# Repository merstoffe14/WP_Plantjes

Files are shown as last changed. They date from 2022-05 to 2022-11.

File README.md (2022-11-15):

# Scientific project: Automated watering system.

For our course "Scientific project" we had to work out a system that automatically waters plants. While my colleague Wolf worked on the Mechanical side of the project, I developed the in-depth control interface (A website) on which the user is able to read out and set different parameters for each individual row of plants. 

With this website, you could also make different watering schedules (time of day, amount, ...) for each individual row of plants.

To realize this I used: Python, FastAPI, HTML, css, javascript, bootstrap, RPi.GPIO, Adafruit_GPIO.SPI, Adafruit_MCP3008

## File explanation

/WP_Plantjes/extra_docs
* RPI_pins_and_commands.txt : A file I used to remember some important commands and the * pins used on the RPI
* WP_Code dikke lijnen.pdf  : A pdf with the code flowchart
* WP_Water flow chart.pdf   : A pdf with the water flowchart
* user_manual_g1.pdf        : [The user manual](https://github.com/merstoffe14/WP_Plantjes/blob/main/extra_docs/user_manual_g1.pdf)

/WP_Plantjes/code/rpi:
* data.json        : the file where the rpi saves its data
* howto.html       : the webpage that shows when you press the how to button.
* index.html       : the homepage of the system
* init_data.json   : when there is no data.json, it copies this one. it is filled with placeholder data.
* main.py          : The main code, receives and sends everything to and from the web interface and communicates the data to the runner.py
* models.py        : Define different objects
* requirements.txt : The packages needed for the software to work (not all of these are needed, there are unused packages.)
* runner.py        : receives data from main.py. calculates and schedules everything. 

/WP_Plantjes/3d
* kast_schets.ipt  : A 3d model of the first idea.

/WP_Plantjes/images
* a couple of images of the finished/WIP project.

## User manual
We also had to make a user manual [user manual](https://github.com/merstoffe14/WP_Plantjes/blob/main/extra_docs/user_manual_g1.pdf)

## The challanges:

* We had to work with 220, 12, 5 and 3.3 Volt to control and power all the different systems.
* Converting a lot of analog signals (moisture sensors) to digital and sending those to the RPI using SPI
* Having 4, independently controlled, levels. 

## Pictures
Front view            |  Side view
:-------------------------:|:-------------------------:
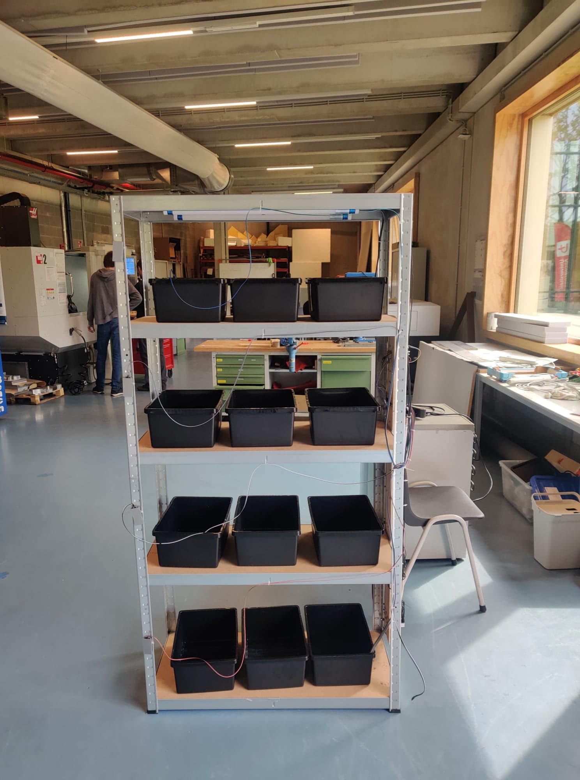
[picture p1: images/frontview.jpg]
The front view
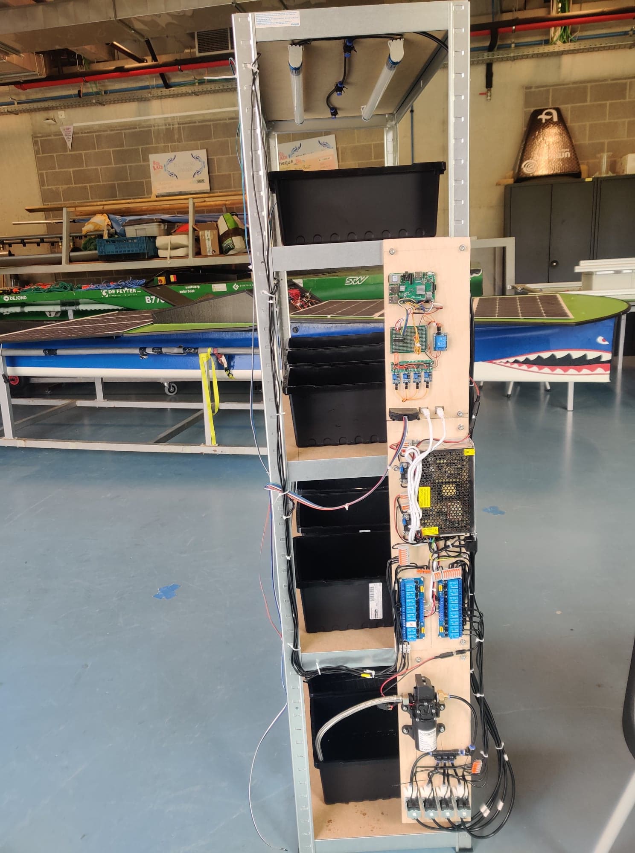
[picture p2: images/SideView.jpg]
The side view
|

Control circuitry            |  Power supply/management
:-------------------------:|:-------------------------:
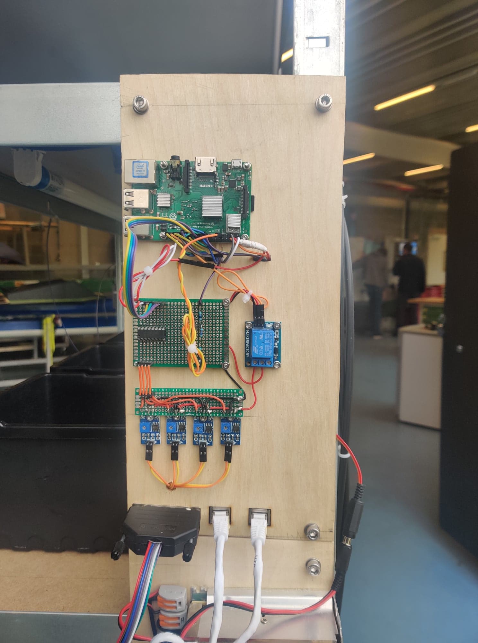
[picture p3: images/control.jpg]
Control circuits
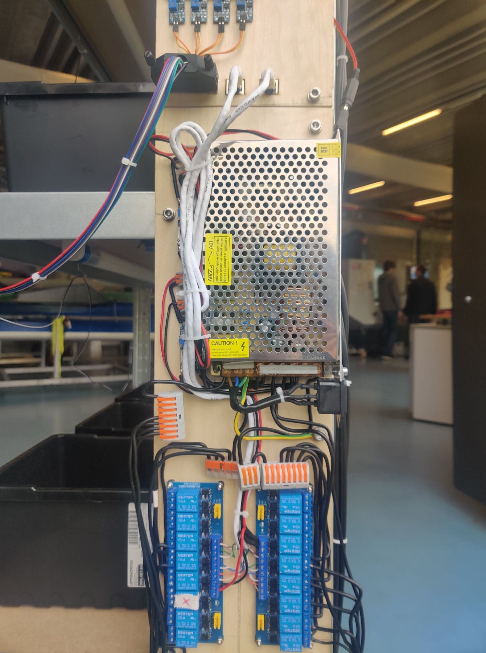
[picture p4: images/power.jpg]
Power
|

Pump and valves            |  Website
:-------------------------:|:-------------------------:
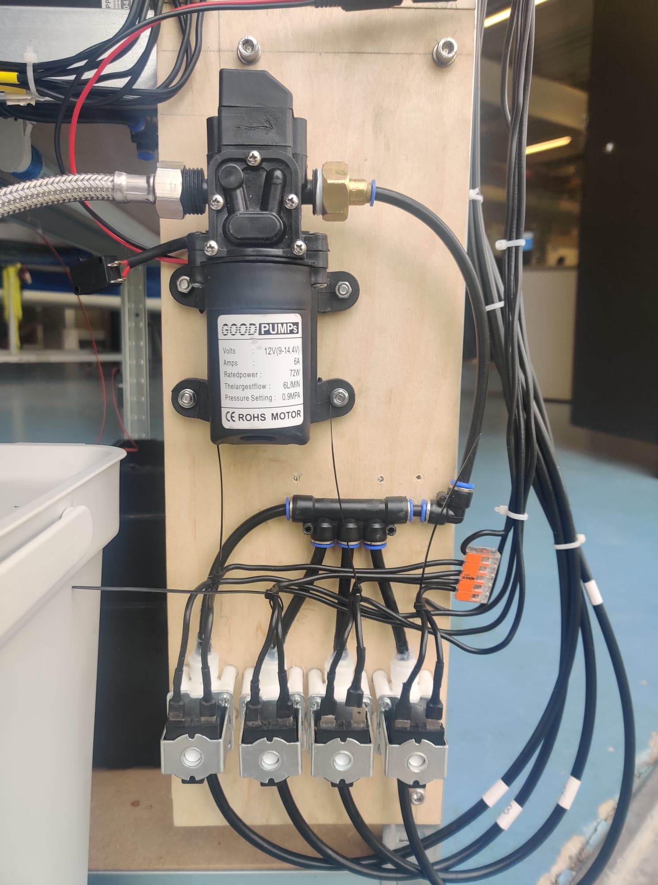
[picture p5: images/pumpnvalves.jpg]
Pump and valves
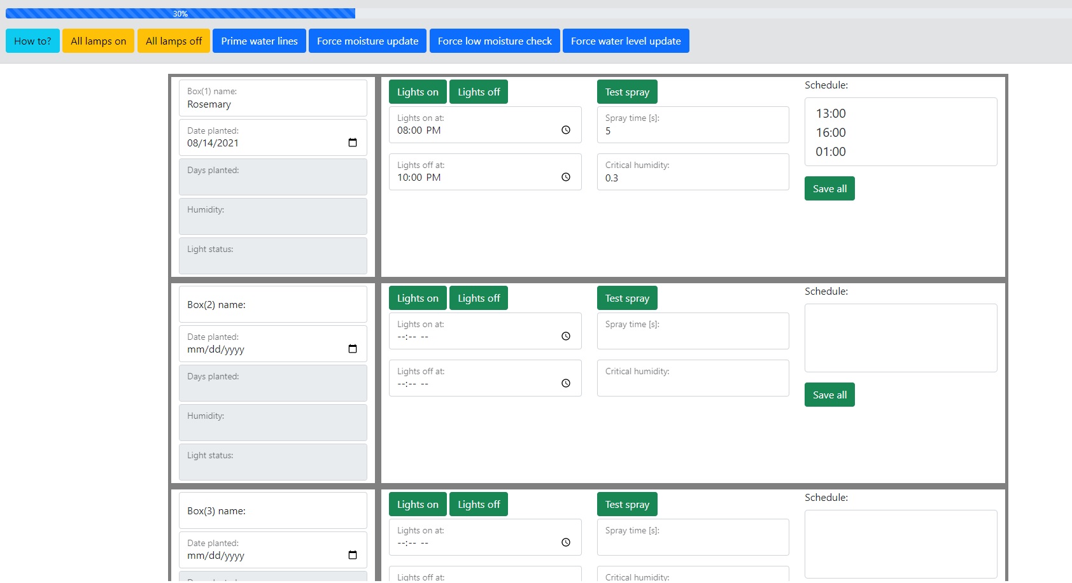
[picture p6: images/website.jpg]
Website
|

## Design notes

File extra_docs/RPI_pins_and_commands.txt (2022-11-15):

dit gaat om kabels niet verdiepen

lamp 1: 25
lamp 2: 24
lamp 3: 7
lamp 4: 1

water 1: 0 13
water 2: 5 0
water 3: 6 5 
water 4: 13 6

pomp: 19 

--MCP3008--
CLK: 4
Dout: 17
Din: 27
CS/SHDN: 22

ENABLE SENSORS: 26?

--Ultrasone--
Echo: 2
Trig: 3

raspi-config spi enablen

python -m uvicorn main:app --reload

python -m uvicorn --host 192.168.0.225 main:app

bij reset niet vergeten om account root te maken, en dan root ssh te enablen

ifconfig

sudo iwlist wlan0 scanning | grep ESSID

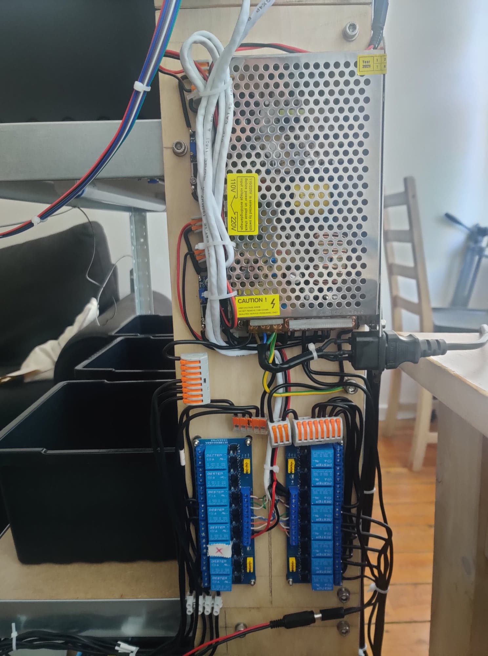
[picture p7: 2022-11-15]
images/280755883_1665423320491643_1910680200256535256_n.jpg

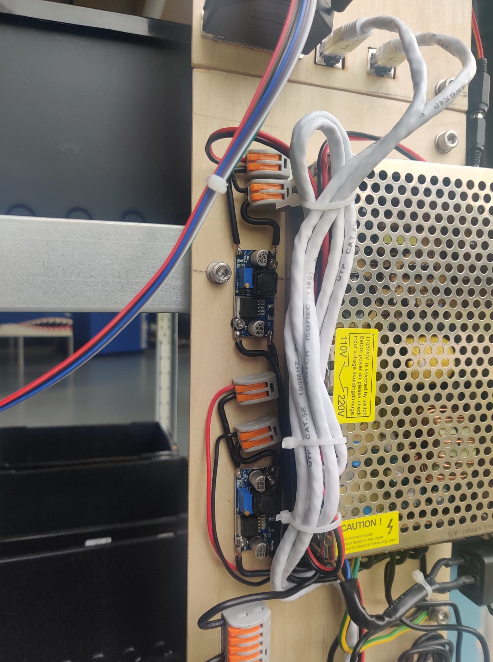
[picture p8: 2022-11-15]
images/281511996_937265423658703_378714550519950564_n.jpg

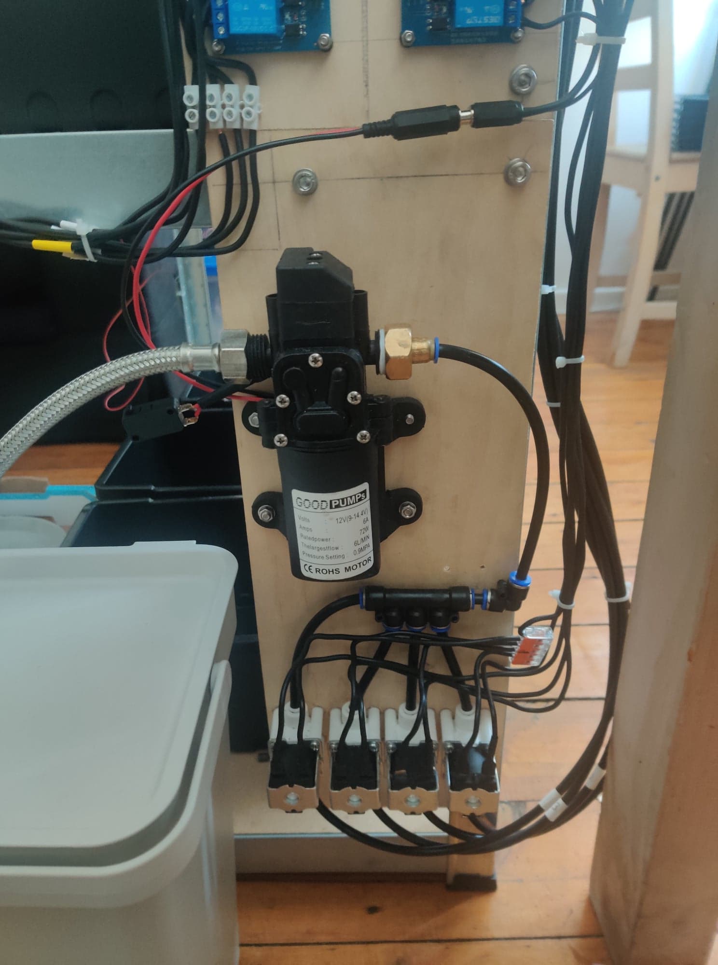
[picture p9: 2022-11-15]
images/281193448_560246208773453_215113502321909703_n.jpg

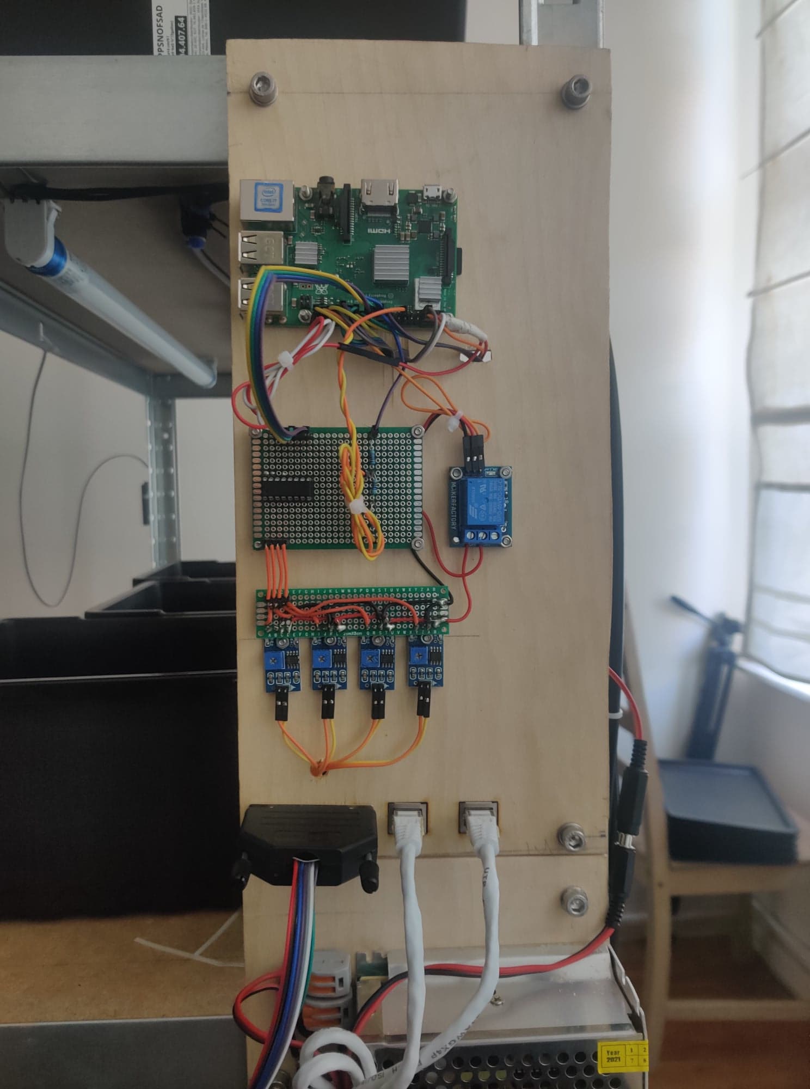
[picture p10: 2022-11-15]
images/281861318_307933138194621_1565468050905774304_n.jpg

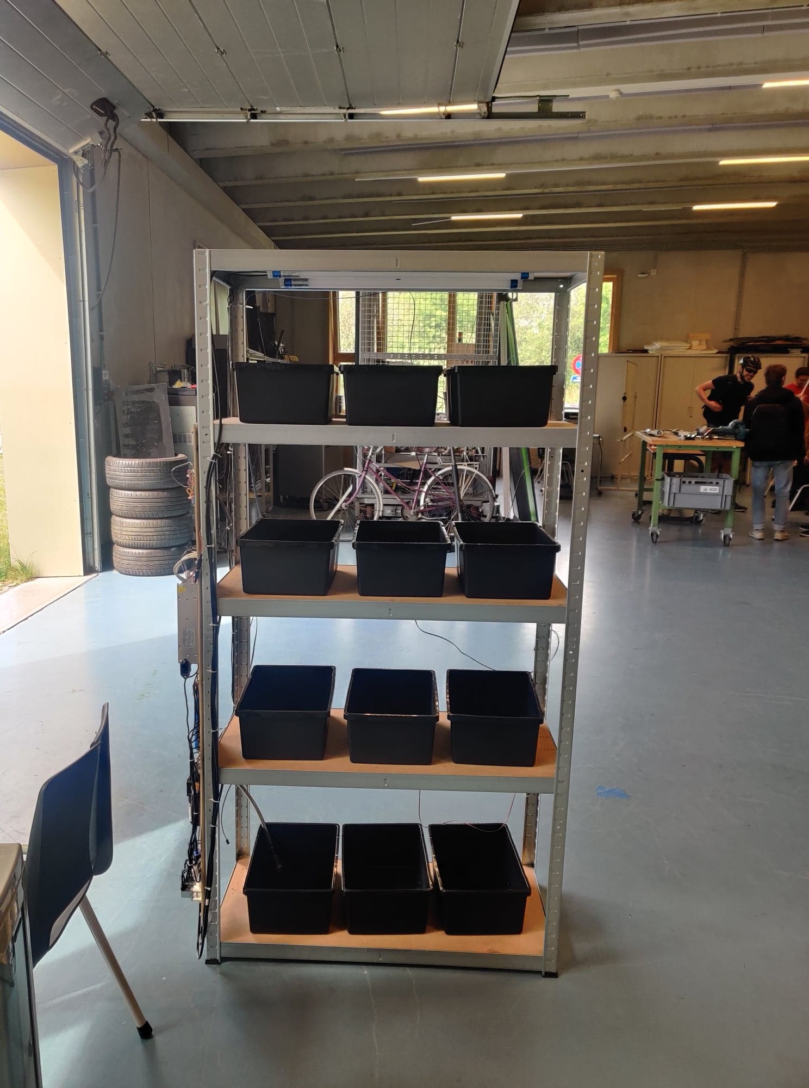
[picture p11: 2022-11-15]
images/281406808_340187884884286_5686262191399596575_n.jpg

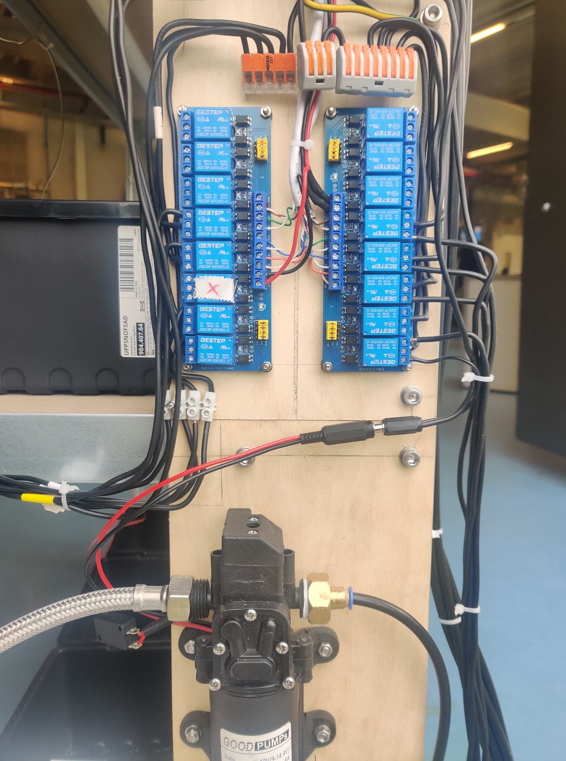
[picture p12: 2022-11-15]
images/281621734_1046185666317548_286411290797942656_n.jpg

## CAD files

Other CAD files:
3d/kast_schets.ipt

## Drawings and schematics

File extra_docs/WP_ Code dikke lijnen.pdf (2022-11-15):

## Loop User input

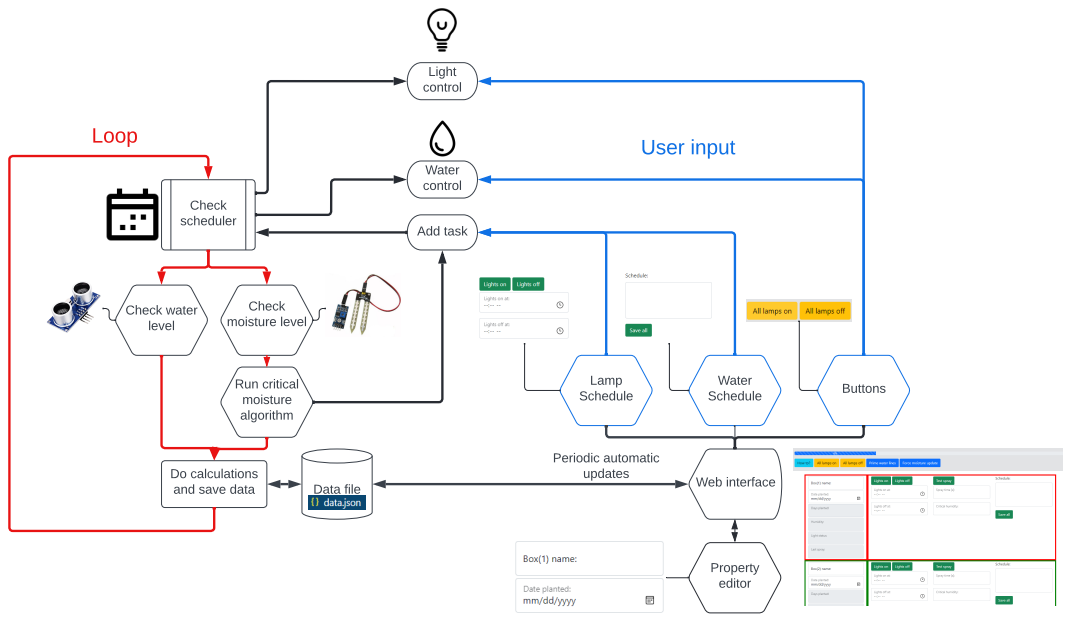
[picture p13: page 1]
Check scheduler; Add task; Check moisture level; Check water level; Light control; Water control; Run critical moisture algorithm; Do calculations; and save data; Data file; Web interface; Periodic automatic updates; Lamp Schedule; Water Schedule; Buttons; Property editor

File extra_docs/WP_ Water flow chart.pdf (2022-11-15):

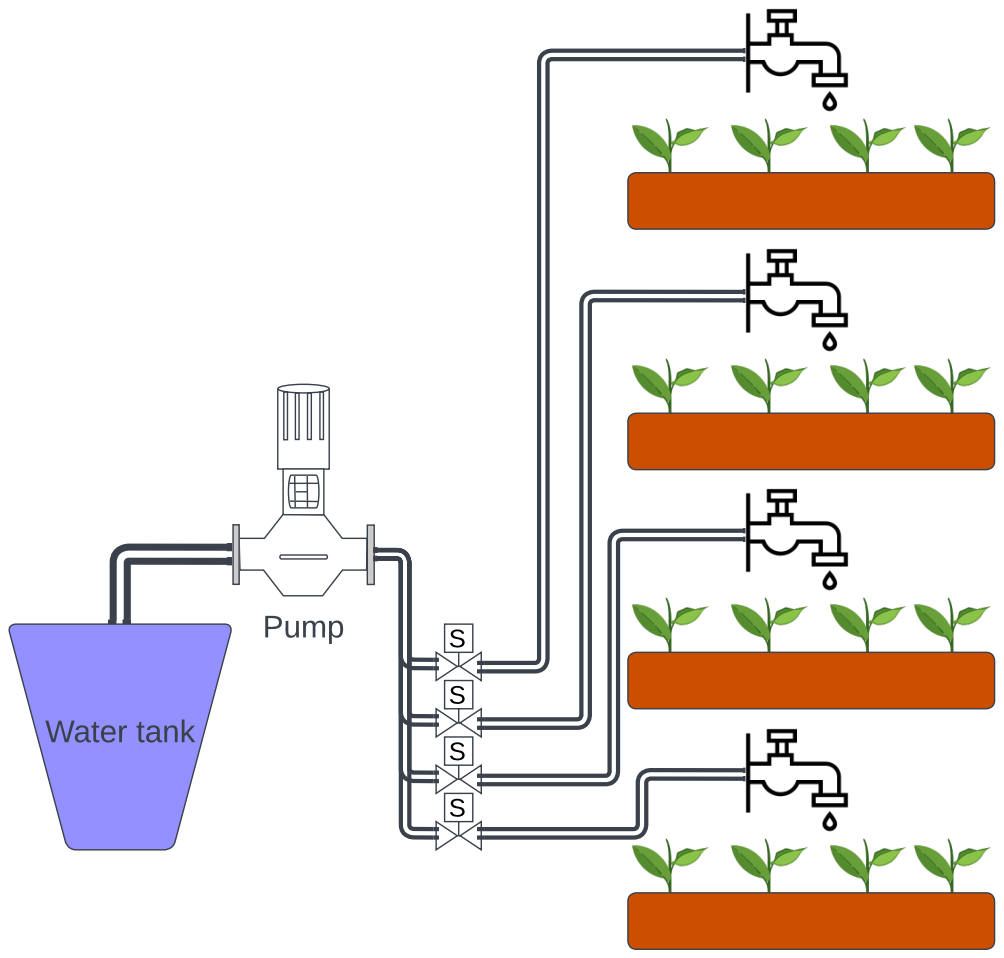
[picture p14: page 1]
SSSS

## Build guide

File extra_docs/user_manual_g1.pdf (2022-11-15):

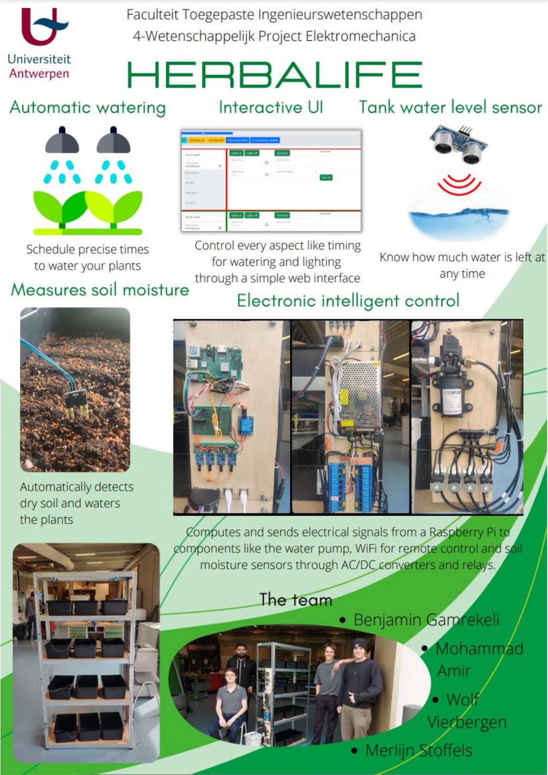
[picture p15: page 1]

# Herbalife: User manual

Table of Contents

## 1. Set up

a. Hardware set up
The set-up was not yet designed to be used by everyone; some technical knowledge is required. This could be made easier, but that was not the focus of this project.
1. Use your phone to create a hotspot with SSID “wififorpi” and password “wififorpi”
2. Plug in the power cord.
3. Wait for the lamps to turn on (Level 2 or level 3)
4. The pi automatically connects to the hotspot.
b. Software set up
1. Connect to the same network as the raspberry pi (your own hotspot).
2. Find the Pi’s local network address using a network scanner
3. Using a command line, SSH into the using username “pi” and password “raspberry”

Example: ssh pi@192.168.0.225

4. Now that you are in the pi, run these commands:
>>cd /rpi
>>python -m uvicorn –host “insert pi ip” main:app
5. Browse to the Pi’s local network address with port 8000.

Example 192.168.0.225:8000

## 2. General usage

a. Web interface overview

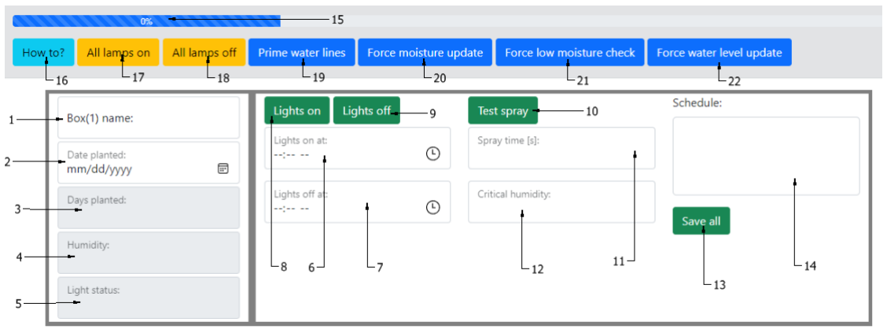
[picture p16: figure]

Everything from number 1 to number 14 is repeated 4 times across the web interface. All these controls/Text fields are level specific. Level 1 is the shelf at the top and level 4 is the shelf at the bottom.

Everything from number 15 to number 22 is not level specific. These are general controls and stay at the top of the web interface even when scrolling down.

1. Box name
The name of the box/level, the user can change this at any time.
2. Date planted
The date the user planted their plants, this can be changed at any time
3. Days planted
The number of days since the “date planted” this gets calculated and changed automatically a couple of seconds after changing “date planted”
4. Moisture level
A number between 0 and 1 where 1 is the most humid state of the soil used and 0 the driest. This can be calibrated (Read “calibration”)
5. Light status
Displays the light status
6. Lights on time
The lights turn on at this time, the user can edit this at any time. (Read “Scheduling water”)
7. Lights off time
The lights turn on at this time, the user can edit this at any time. (Read “Scheduling water”)
8. “Lights on” button
Turns the lights on
9. “Lights off” button
Turns the lights off
10. “Test spray” button
Sprays water for a time equal to “Spray time”(11)

11. Spray time
Used to set the amount of seconds a test spray(10) or scheduled spray(14) will spray

12.Critical moisture
If the moisture level drops below this value, the level will automatically be sprayed for a “spray time”(11) amount of seconds. This value has to be between 0 and 1
13. “Save all” button
This button saves every change made, it is very important. It will not work when one of the fields is empty or contains unfitting information for example: “Spray time = q”. The save button will not work because the character “q” is not a whole number. This button will only save the data from the specific level where the button is pressed.
14. Schedule field
This field is used to schedule the automatic watering. (Read “Scheduling water”)
15.Water level indicator
This bar indicates the water level as a percentage between 0 and 100 AND as a progress bar.
16. “How to?” button
This button shows this manual.
17. “All lamps on” button
Turn on ALL the lights
18. “All lamps off” button Turn off ALL the lights
19.“Prime water lines button” This fills the lines with water. All the valves will be opened when this button is pressed, so if the lines are filled with water, there will be coming water out of most of the nozzles (Not all of them because the pump head is too low to do that).
20. “Force moisture update” button This button is for debug/presentation purposes, it overrides the timer and measures the moisture level.
21. “Force low moisture check” button
This button is for debug/presentation purposes, it overrides the timer and checks if the measured moisture level is under the critical moisture(12) value given by the user.
22. “Force water level update” button
This button is for debug/presentation purposes, it overrides the timer and measures the water level.

c. Scheduling water
To schedule automatic watering, add times to the “schedule field”(14). The times need to be in a specific format for the program to register them. If they are in the wrong format, You will be able to save, but the watering won’t be scheduled. The correct format is:

HH:MM.

For example: 01:00, 21:02, 19:35.

To add more then 1 scheduled watering moment, just press enter after the first inserted time, and type a new time on the new line. For example:

01:00
21:02

To set how long you want each watering event to be, edit the “spray time”(11) value Don’t forget to press “save all”(13) after setting the schedule.

d. Scheduling light
To schedule automatic light control, add times to the “Lights on time”(6) and “Lights of time”(7) fields. The times need to be in a specific format for the program to register them. If they are in the wrong format, You will be able to save, but the watering won’t be scheduled. The correct format is:

HH:MM.

For example: 01:00, 21:02, 19:35.
Don’t forget to press “save all”(13) after setting the times.
f. Timings
- Data refresh rate: determines how often the web interface gets data from the Pi (standard = 5 s)
- Water level refresh rate: determines how often the pi measures the water level (standard = 20 s)
- Moisture refresh rate: determines how often the pi measures the moisture level (standard = 10 minutes)
- Critical moisture refresh rate: determines how often the pi calculates if the moisture level is too low. (standard = 30 m)

All these values can be edited in /index.html at line 486-489

g. Calibration
- To calibrate the moisture sensors or the water level sensor, edit the values on line 56-59 in runner.py
- To edit the pins used by the raspberry pi, edit the values on line 31-46 in runner.py
- To edit various pump settings, edit the values on line 54-55 in runner.py

## 3. Troubleshooting

Type | Nr | Problem | Possible cause | Solution Hardware
1 | Water doesn’t pump | Intake pulls air instead of water | Seal intake port and intake tube of the pump
2 | | Water tank empty | Fill water tank
3 | Water does not reach correct level | Valves are connected in the wrong order | Connect valves in correct order
4 | Water leaks while pump is working | The pump is on but the (wrong) valve remains closed | Order of relay switching by using the lights on the relay board The valve should always open before the pump start
5 | Sensors give no/inaccurate results | Visible oxidation on moisture sensor: sensor degradation | Replace sensor
6 | | Sensor cable is not plugged in | Plug in the sensor cable
7 | Lights or valves don’t turn on | Relay cables not plugged in or switched | Connect the cables and check labels on connector head

8
9 | Wrong lights/valves turn on | Pins are placed incorrectly on Raspberry pi | Check pin placement on Raspberry Pi
10 | | Code contains the wrong variable | Check pin variables in runner.py
11 | Moisture levels is not correct | Wrong pin is assigned in code or badly calibrated | Change moisture pin variables in runner.py
12 | Water level is not correct | Wrong pin is assigned in code or badly calibrated | Change water level variables in runner.py

## Software

## 4. Software

## a. Schematic

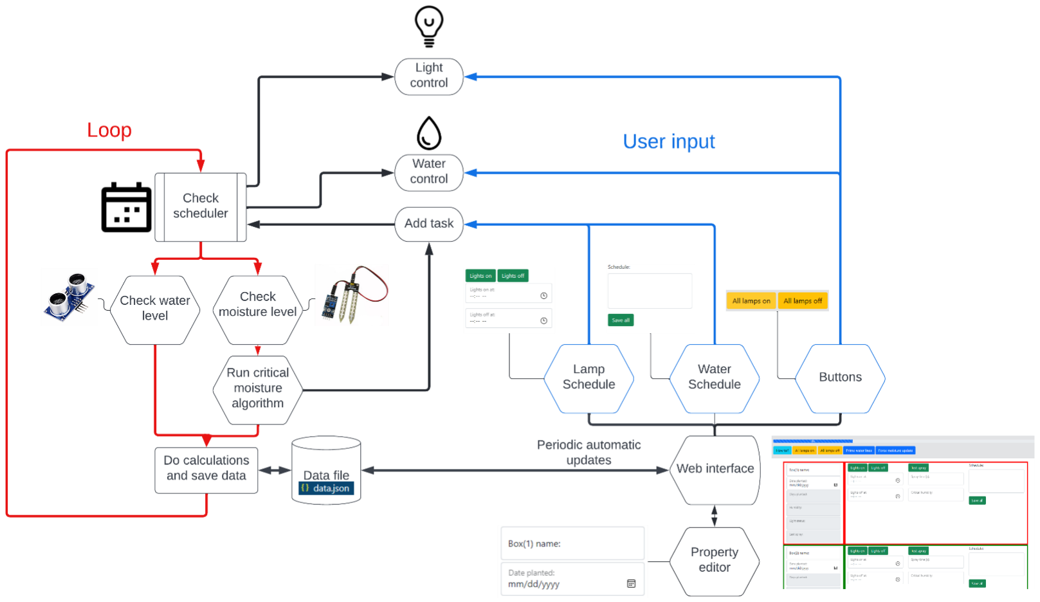
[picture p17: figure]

The red loop runs automatically which gets and processes sensor data. It also checks the schedule, if there is a task in the schedule, then it will be executed (watering plants or turning on/off the lights). The blue part is the user input.

## 5. Electrical system

a. Schematic

Each level contains the same components.

Here is a schematic for what the connections look like on each level:

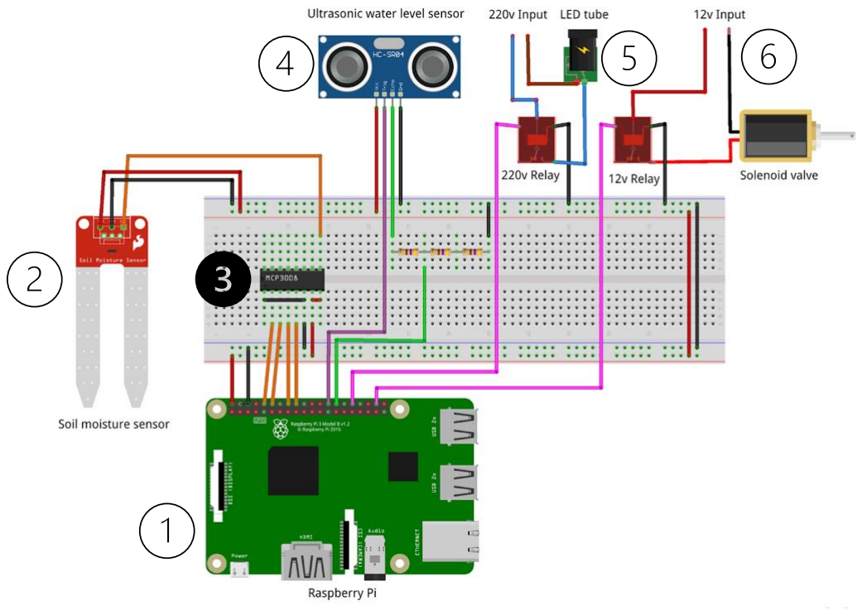
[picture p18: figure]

1. Raspberry Pi: it’s the brains of the automated grow box and runs Linux Raspbian.
2. Soil moisture sensor: measures the moisture level of soil and sends that data to an MCP3008 (5.a.3).
3. MCP3008: converts and analogue signal to a digital one, so the Raspberry Pi (5.a.1) can interpret that data.
4. Ultrasonic water level sensor: it measures the time for a soundwave to bounce off of the surface of water and back. The RPI (5.a.1) sends a 5v signal to the “Trig” pin, it receives a 5v signal back from the “Echo” pin. These 5v get stepped down with a voltage divider to 3.3v. This way the RPI (5.a.1) can receive it safely.
5. 220v Relay & LED tube: The 220v relays are connected to LED tubes from Phillips that have a T8 connection (often seen used on fluorescent light tubes).
6. 12v Relay & Solenoid valve: The 12v relays are connected to the Solenoid valves, which make sure the correct levels get water.

## 6. Water system

a. Schematic

This is a simplified overview of how all the water line connections are made.

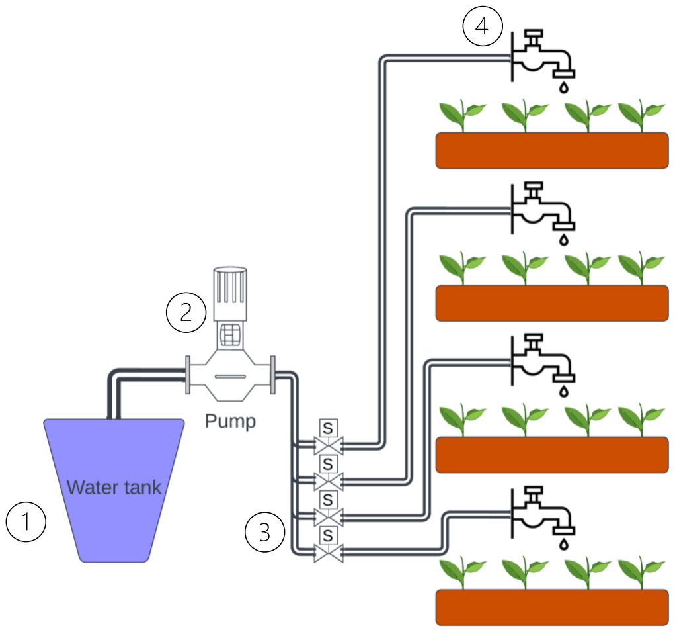
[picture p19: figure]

1. Water tank: it has a capacity of 9L when full and contains one hole for the pump (6.a.2), and another for the Ultrasonic water level sensor (5.a.4).
2. Pump: a 12v pump that draws a maximum of 72W and can create a pressure head of 90 metres (0,9MPa). It is rated for a flowrate of about 6L/min. The pipe fittings on each end are 3/4th inch pipe threads. On the intake side the pump also features a water filter at the end of the pipe.
3. Water splitter and Solenoids: the water splitter (1 in; 4 out) divides the water over the four solenoid valves, which operate at 12v and rest in a NC state.
4. Water drip lines: spread water over the whole soil area of that level.

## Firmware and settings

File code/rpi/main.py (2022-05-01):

from datetime import datetime
from fastapi import FastAPI, Response
from fastapi.responses import HTMLResponse
import asyncio
from models import PlantBox
from models import PlantBoxDataReceive
from runner import BackgroundRunner
from fastapi.responses import JSONResponse
from pydantic import BaseModel
import threading


"""
Code for 4-Scientific-project.
By Merlijn Stoffels

If I had more time, I would rewrite a big part of this program to make things more efficient.
"""


app = FastAPI()
# The idea was that most of the logic is handled by runner.py and the javascript. main.py is just a "Bridge" (?) between the two.
runner = BackgroundRunner()

# All of these endpoints are simple and understandable (I hope?) so there is no extra explanation


@app.on_event('startup')
async def app_startup():
    await runner.load_data()
    thread = threading.Thread(target=runner.run_main)
    thread.start()


@app.get("/", response_class=HTMLResponse)
async def read_root():
    with open("index.html", "r") as f:
        return HTMLResponse(content=f.read(), status_code=200)


@app.get("/howto", response_class=HTMLResponse)
async def read_howto():
    with open("howto.html", "r") as f:
        return HTMLResponse(content=f.read(), status_code=200)


@app.get("/gettime")
async def read_gettime():
    now = datetime.now()
    current_time = now.strftime("%H:%M:%S")
    return current_time


@app.get("/getwaterlevel")
async def read_getwaterlevel():
    percentage = await runner.getwaterlevel()
    return percentage


@app.get("/getdata")
async def read_getdata():
    await runner.load_data()
    payload = runner.plant_boxes
    return payload


@app.post("/upall")
async def update_plantbox_name(plantbox_data: PlantBoxDataReceive, id: int):

    # Validate
    if str(id) not in runner.plant_boxes:
        return JSONResponse(status_code=404, content={"error": "Plantbox not found"})

    stored_box = runner.plant_boxes[str(id)]
    stored_box.user_update(plantbox_data)
    await runner.save_data()
    runner.reschedule(id)

    return Response(status_code=200)


@app.get("/lamp")
async def lamp(id: int, status: int):
    # Validate
    if str(id) not in runner.plant_boxes:
        return JSONResponse(status_code=404, content={"error": "Plantbox not found"})
    runner.lamp(id, status)
    await runner.save_data()
    return Response(status_code=200)


@app.get("/spraytest")
def spraytest(id: int):
    # Validate
    if str(id) not in runner.plant_boxes:
        return JSONResponse(status_code=404, content={"error": "Plantbox not found"})
    runner.spray(id, runner.plant_boxes[str(id)].spraytime)


@app.get("/prime")
async def prime():
    await runner.prime()


@app.get("/alllamps")
async def alllamps(status: int):
    await runner.all_lamps(status)


@app.get("/getmoisture")
async def getmoisture():
    await runner.getMoisture()


@app.get("/critmoist")
async def critmoist():
    await runner.critMoist()

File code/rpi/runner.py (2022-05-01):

import asyncio
from pickle import FALSE
from xml.dom.minidom import Element
from models import PlantBox
import os
import shutil
import jsonpickle
from datetime import datetime
import schedule
import time
import re
import RPi.GPIO as GPIO
import Adafruit_GPIO.SPI as SPI
import Adafruit_MCP3008




class BackgroundRunner:
    def __init__(self):

        self.plant_boxes = {
            1: PlantBox(1),
            2: PlantBox(2),
            3: PlantBox(3),
            4: PlantBox(4)
        }

    def run_main(self):

        # Define all pins:

        self.moistPower_pin = 26 

        self.trigger_pin = 3
        self.echo_pin = 17

        self.lamp_1_pin = 24
        self.lamp_2_pin = 25
        self.lamp_3_pin = 7
        self.lamp_4_pin = 1 
        self.valve_1_pin = 5
        self.valve_2_pin = 6
        self.valve_3_pin = 13
        self.valve_4_pin = 0
        self.pump_pin = 19

        # Put pins in pinarrays (for ease of use in loops)

        self.lamppin_array = [self.lamp_1_pin, self.lamp_2_pin, self.lamp_3_pin, self.lamp_4_pin]
        self.valvepin_array = [self.valve_1_pin, self.valve_2_pin, self.valve_3_pin, self.valve_4_pin]

        # Define various settings
        self.time_pump_safety = 0.5 # [s]
        self.time_pump_prime = 0 # [s]
        self.TANK_FULL = 3 # [cm]
        self.TANK_EMPTY = 30 # [cm]
        self.MOISTURE_MAX = 750 # [ul]
        self.MOISTURE_MIN = 220 # [ul]
        
        # Set GPIO modes
        GPIO.setmode(GPIO.BCM)
        GPIO.setwarnings(False)
        chan_list = [self.lamp_1_pin, self.lamp_2_pin, self.lamp_3_pin,  self.lamp_4_pin, self.valve_1_pin, self.valve_2_pin, self.valve_3_pin, self.valve_4_pin, self.pump_pin]  
        GPIO.setup(chan_list, GPIO.OUT)
        GPIO.setup(self.trigger_pin, GPIO.OUT)
        GPIO.setup(self.echo_pin, GPIO.IN)
        GPIO.setup(self.moistPower_pin, GPIO.OUT)
        GPIO.output(self.trigger_pin, GPIO.LOW)

        # Set up ADC mcp3008 (Hardware mode)
        HW_SPI_PORT = 0  # Set the SPI Port. Raspi has two.
        HW_SPI_DEV = 0  # Set the SPI Device
        self.mcp = Adafruit_MCP3008.MCP3008(spi=SPI.SpiDev(HW_SPI_PORT, HW_SPI_DEV))


        # Run the loop, I planned on using this loop more but in the end I only used it to run the scheduler
        while True:
            time.sleep(1)
            self.loop()

    # Loading data from locally saved file

    async def load_data(self):
        print("Loading data")

        # Check if data.json exists, if not copy from hardcoded initial template.
        try:
            if not os.path.exists('data.json'):
                shutil.copyfile('init_data.json', 'data.json')
        except Exception as e:
            raise Exception("Initial data json is missing!") from e

        # Read database in memory.
        with open('data.json', 'r') as json_file:
            json_data = json_file.read()
            self.plant_boxes = jsonpickle.decode(json_data)
        for i in range(1, 5):
            self.reschedule(i)

    # Saving data to locally saved file

    async def save_data(self):
        print("Saving data")
        with open('data.json', 'w') as json_file:
            json_file.write(jsonpickle.encode(self.plant_boxes))

# It would have been easier if status was of type BOOL, but I had some problems with that.
    def lamp(self, id: int, status: int):
        # Setting the light_status var for the shelf
        if status == 1:
            self.plant_boxes[str(id)].light_status = 1
        elif status == 0:
            self.plant_boxes[str(id)].light_status = 0
        else:
            print("given status is not a valid status for lamp")

        # Actually turning the lamp on/off
        GPIO.output(self.lamppin_array[id-1], status)
        print("Turning lamp " + str(id) + " to " + str(status))

        
    # if this function is called via test spray it does not run in a separate thread and then everything stops for a spraytime number of seconds (Notice the clock on the web interface)
    # A solution would be to make this function async, but then I get problems in the scheduler with lambda.
    # The save_data is not called async either. This causes a warning in the console.
    def spray(self, id: int, spraytime: int):
        print("Spraying at " + str(id) + " for: " + str(spraytime) + " seconds")

        # Valve open
        GPIO.output(self.valvepin_array[id-1], True)
        # Small safety time, to open valve fully
        time.sleep(self.time_pump_safety)
        # Turn on pump
        GPIO.output(self.pump_pin, True)
        # Let pump run for spraytime + a priming time
        time.sleep(spraytime + self.time_pump_prime)
        # Turn of pump
        GPIO.output(self.pump_pin, False)
        # Wait for safety
        time.sleep(self.time_pump_safety)
        # Close valves
        GPIO.output(self.valvepin_array[id-1], False)
        print("Spray done")

        self.save_data()

    # The logic for this sensor is from: https://www.freva.com/nl/hc-sr04-ultrasone-sensor-gebruiken-met-raspberry-pi/
    async def getwaterlevel(self):

        print("Measuring water distance")
        distance = []
        for i in range(5):
            time.sleep(0.1)
            GPIO.output(self.trigger_pin, GPIO.HIGH)
            time.sleep(0.00001) 
            GPIO.output(self.trigger_pin, GPIO.LOW)

            while GPIO.input(self.echo_pin) == 0:

                    pulse_start_time = time.time()
            while GPIO.input(self.echo_pin)==1:

                    pulse_end_time = time.time()

            pulse_duration = pulse_end_time - pulse_start_time
            distance.append(round(pulse_duration * 17150, 2))
            

        # Take average of 5 measurements. This is an attempt at decreasing the constant small updates to the progress bar, if this is not sufficient, I will use a rolling avg.
        avg = sum(distance)/len(distance)
        print("Distance:",avg,"cm")
        tank_level = 1 - (avg-self.TANK_FULL)/(self.TANK_EMPTY-self.TANK_FULL)
        if (tank_level > 1):
            tank_level = 1
        elif (tank_level < 0):
            tank_level = 0

        print(tank_level)
        return tank_level

    async def all_lamps(self, status):
        for x in range(4):
            GPIO.output(self.lamppin_array[x], status)

    # This function exsists to get some water in the lines.
    async def prime(self):
        for x in range(4):
            GPIO.output(self.valvepin_array[x], True)
        time.sleep(self.time_pump_safety)
        GPIO.output(self.pump_pin, True)
        time.sleep(0.5)
        GPIO.output(self.pump_pin, False)
        for x in range(4):
            GPIO.output(self.valvepin_array[x], False)


    # This function can be way more efficient.
    # It takes 10 measurments per sensor and takes the avg.
    async def getMoisture(self):
        GPIO.output(self.moistPower_pin, GPIO.HIGH)
        moistlist = [[],[],[],[]]
        moistval = []
        moistperc = []
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

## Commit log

2022-02-18 Creante plant_software_0.1.ino
    Gestart met het werken aan de basis van de arduino code: Een ID opslaan en lezen van de EEPROM
2022-03-04 Started working on save all button
2022-04-15 added gpio for pump/valves/lamps
2022-05-01 Finished code
    This is the finished code. there are a couple of known bugs. but this version is ok
    [main.py, models.py, runner.py]
2022-11-15 Added all the files
    [kast_schets.ipt]
